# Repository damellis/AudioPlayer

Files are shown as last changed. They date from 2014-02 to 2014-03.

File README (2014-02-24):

Simple, Arduino-compatible audio player, designed to be produced using
Seeedstudio's PCBA service (http://www.seeedstudio.com/service/index.php).
Only uses parts from the Seeedstudio open parts library (OPL), including
an ATmega328, micro-SD card slot, lipo connector and charging circuit,
headphone jack, etc. The full list of parts in the OPL can be found here:
http://www.seeedstudio.com/wiki/Open_parts_library

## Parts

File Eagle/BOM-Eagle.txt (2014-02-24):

"Part";"Value";"Device";"Package";"Description";"";
"C1";"100nF";"C-0603";"C0603";"";"";
"C2";"100nF";"C-0603";"C0603";"";"";
"C3";"22pF";"C-0603";"C0603";"";"";
"C4";"22pF";"C-0603";"C0603";"";"";
"C5";"22uF";"C-POLAR-B";"AVX-B";"";"";
"C6";"10uF";"C-POLAR-A";"AVX-A";"";"";
"C7";"10uF";"C-POLAR-A";"AVX-A";"";"";
"C8";"1uF";"C-0805";"C0805";"";"";
"C9";"1uF";"C-0805";"C0805";"";"";
"C10";"100nF";"C-0603";"C0603";"";"";
"J1";"MICRO-SDCARD-CONNECTOR-3300060P1";"MICRO-SDCARD-CONNECTOR-3300060P1";"9P-SMD-W-RING";"Micro SD Card";"";
"J2";"JST-2P-SMD-PW-3410050P1";"JST-2P-SMD-PW-3410050P1";"2P-SMD-2.0-90D";"";"";
"J3";"MICRO-USB-5P-340015001";"MICRO-USB-5P-340015001";"B-SMD-5P";"ST-USB-001E：MICRO USB B SMD R/A";"";
"J4";"CONNECTOR-HEADER-2X3P-3460180P1";"CONNECTOR-HEADER-2X3P-3460180P1";"2X3P-2.54-2.54-11.6-3.0-BLACK-MALE";"";"";
"J5";"AUDIO-CONNECTOR-6P-SMD-3440030P1";"AUDIO-CONNECTOR-6P-SMD-3440030P1";"6P-SMD-3.5";"";"";
"J6";"SCREW-TERMINAL-2P-3470070P1";"SCREW-TERMINAL-2P-3470070P1";"2P-3.5";"";"";
"J7";"CONNECTOR-HEADER-6P-3460650P1";"CONNECTOR-HEADER-6P-3460650P1";"1X6P-2.54-2.54-11.6-3.0-BLACK-MALE";"";"";
"J8";"CONNECTOR-HEADER-6P-3460270P1";"CONNECTOR-HEADER-6P-3460270P1";"1X6P-2.54-8.5-BLACK-FEMALE";"";"";
"J9";"CONNECTOR-HEADER-10P-3460170P1";"CONNECTOR-HEADER-10P-3460170P1";"1X10P-2.54-8.5-YELLOW-FEMALE";"";"";
"J10";"CONNECTOR-HEADER-8P-3460290P1";"CONNECTOR-HEADER-8P-3460290P1";"1X8P-2.54-8.5-BLACK-FEMALE";"";"";
"J11";"CONNECTOR-HEADER-8P-3460290P1";"CONNECTOR-HEADER-8P-3460290P1";"1X8P-2.54-8.5-BLACK-FEMALE";"";"";
"K1";"BUTTON-4P-3100010P1";"BUTTON-4P-3100010P1";"4P-SMD-6.0X6.0X5.0H";"";"";
"R1";"4.7K";"R-0603";"R0603";"";"";
"R2";"10K";"R-0603";"R0603";"";"";
"U1";"ATMEGA328P-AU-1030060P1";"ATMEGA328P-AU-1030060P1";"TQFP32";"8-bit AVR";"";
"U2";"CN3065-1320040P1";"CN3065-1320040P1";"DFN8";"USB-Compatible Lithiumt-Ion Battery Charger with Thermal Regulation";"";
"U3";"XC6206-3.3-1300260P1";"XC6206-3.3-1300260P1";"SOT23";"LOW ESR Cap.Compatible Positive Voltage Regulators";"";
"X1";"CRYSTAL-0500290P1";"CRYSTAL-0500290P1";"2P-SMD-5.0X3.2";"";"";

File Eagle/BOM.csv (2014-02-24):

SKU | Qty | Parts
0100020P1 | 3 | C1,C2,C10
0100620P1 | 2 | C3,C4
0130240P1 | 1 | C5
0130050P1 | 2 | C6,C7
0100440P1 | 2 | C8,C9
3300060P1 | 1 | J1
3410050P1 | 1 | J2
3400150P1 | 1 | J3
3460180P1 | 1 | J4
3440030P1 | 1 | J5
3470070P1 | 1 | J6
3460650P1 | 1 | J7
3460270P1 | 1 | J8
3460170P1 | 1 | J9
3460290P1 | 2 | J10,J11
3100010P1 | 1 | K1
0010030P1 | 1 | R1
0010170P1 | 1 | R2
1030060P1 | 1 | U1
1320040P1 | 1 | U2
1300260P1 | 1 | U3
0500290P1 | 1 | X1

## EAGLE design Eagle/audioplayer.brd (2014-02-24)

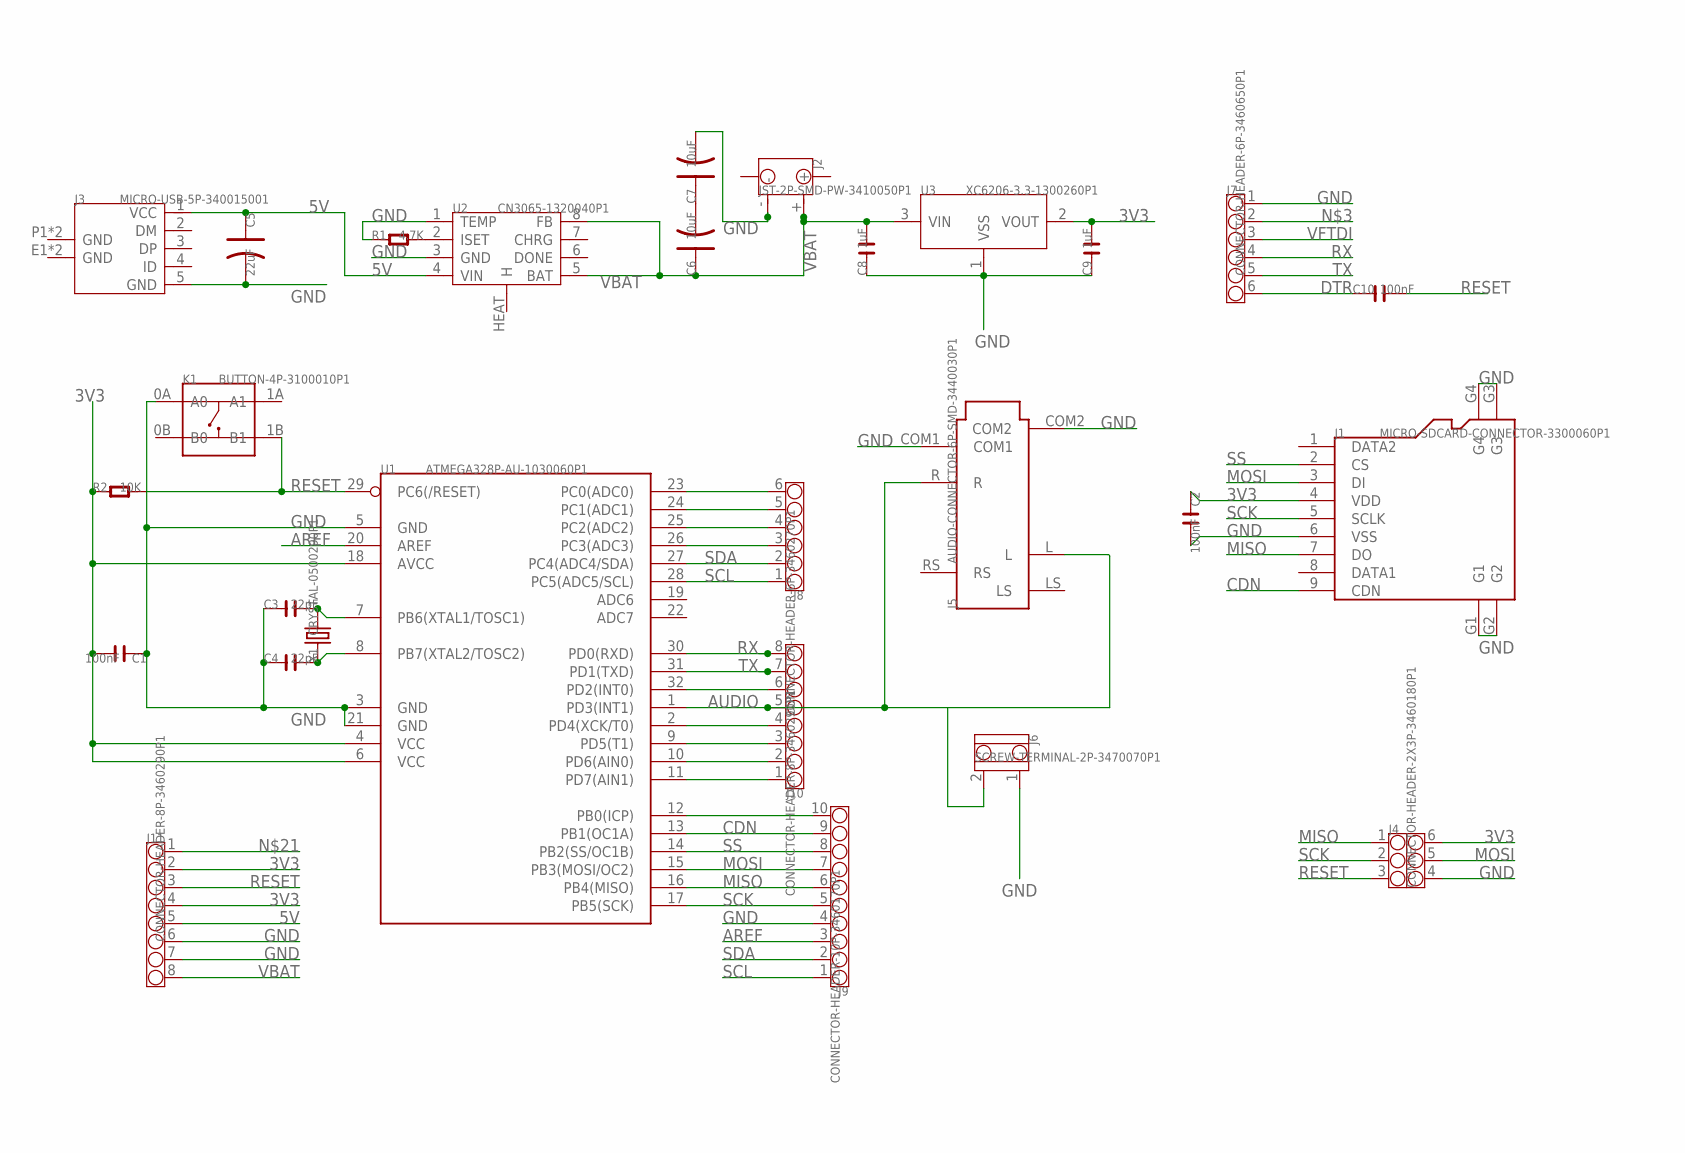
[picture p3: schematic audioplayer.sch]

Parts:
C1, C2, C10: 100nF; C0603
C3, C4: 22pF; C0603
C5: 22uF; AVX-B
C6, C7: 10uF; AVX-A
C8, C9: 1uF; C0805
J1: MICRO-SDCARD-CONNECTOR-3300060P1; 9P-SMD-W-RING
J2: JST-2P-SMD-PW-3410050P1; 2P-SMD-2.0-90D
J3: MICRO-USB-5P-340015001; B-SMD-5P
J4: CONNECTOR-HEADER-2X3P-3460180P1; 2X3P-2.54-2.54-11.6-3.0-BLACK-MALE
J5: AUDIO-CONNECTOR-6P-SMD-3440030P1; 6P-SMD-3.5
J6: SCREW-TERMINAL-2P-3470070P1; 2P-3.5
J7: CONNECTOR-HEADER-6P-3460650P1; 1X6P-2.54-2.54-11.6-3.0-BLACK-MALE
J8: CONNECTOR-HEADER-6P-3460270P1; 1X6P-2.54-8.5-BLACK-FEMALE
J9: CONNECTOR-HEADER-10P-3460170P1; 1X10P-2.54-8.5-YELLOW-FEMALE
J10, J11: CONNECTOR-HEADER-8P-3460290P1; 1X8P-2.54-8.5-BLACK-FEMALE
K1: BUTTON-4P-3100010P1; 4P-SMD-6.0X6.0X5.0H
R1: 4.7K; R0603
R2: 10K; R0603
U1: ATMEGA328P-AU-1030060P1; TQFP32
U2: CN3065-1320040P1; DFN8
U3: XC6206-3.3-1300260P1; SOT23
X1: CRYSTAL-0500290P1; 2P-SMD-5.0X3.2

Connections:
3V3: C1.2, C2.1, C9.2, J1.4 (VDD), J4.6, J11.2, J11.4, R2.1, U1.4 (VCC), U1.6 (VCC), U1.18 (AVCC), U3.2 (VOUT)
5V: C5.+ (1), J3.1 (VCC), J11.5, U2.4 (VIN)
AREF: J9.3, U1.20 (AREF)
AUDIO: J5.L, J5.R, J6.2, J10.5, U1.1 (PD3(INT1))
CDN: J1.9 (CDN), J9.9, U1.13 (PB1(OC1A))
DTR: C10.1, J7.6
GND: C1.1, C2.2, C3.1, C4.1, C5.- (2), C7.- (2), C8.1, C9.1, J1.6 (VSS), J1.G1, J1.G2, J1.G3, J1.G4, J2.-, J3.5 (GND), J4.4, J5.COM1, J5.COM2, J6.1, J7.1, J9.4, J11.6, J11.7, K1.0A (A0), R1.1, U1.3 (GND), U1.5 (GND), U1.21 (GND), U2.1 (TEMP), U2.3 (GND), U3.1 (VSS)
MISO: J1.7 (DO), J4.1, J9.6, U1.16 (PB4(MISO))
MOSI: J1.3 (DI), J4.5, J9.7, U1.15 (PB3(MOSI/OC2))
unnamed: C6.- (2), C7.+ (1)
unnamed: R1.2, U2.2 (ISET)
unnamed: J8.3, U1.26 (PC3(ADC3))
unnamed: J8.4, U1.25 (PC2(ADC2))
unnamed: J8.5, U1.24 (PC1(ADC1))
unnamed: J8.6, U1.23 (PC0(ADC0))
unnamed: J9.10, U1.12 (PB0(ICP))
unnamed: J10.1, U1.11 (PD7(AIN1))
unnamed: J10.2, U1.10 (PD6(AIN0))
unnamed: J10.3, U1.9 (PD5(T1))
unnamed: J10.4, U1.2 (PD4(XCK/T0))
unnamed: J10.6, U1.32 (PD2(INT0))
unnamed: C3.2, U1.7 (PB6(XTAL1/TOSC1)), X1.2
unnamed: C4.2, U1.8 (PB7(XTAL2/TOSC2)), X1.1
RESET: C10.2, J4.3, J11.3, K1.1B (B1), R2.2, U1.29 (PC6(/RESET))
RX: J7.4, J10.8, U1.30 (PD0(RXD))
SCK: J1.5 (SCLK), J4.2, J9.5, U1.17 (PB5(SCK))
SCL: J8.1, J9.1, U1.28 (PC5(ADC5/SCL))
SDA: J8.2, J9.2, U1.27 (PC4(ADC4/SDA))
SS: J1.2 (CS), J9.8, U1.14 (PB2(SS/OC1B))
TX: J7.5, J10.7, U1.31 (PD1(TXD))
VBAT: C6.+ (1), C8.2, J2.+, J11.8, U2.5 (BAT), U2.8 (FB), U3.3 (VIN)
VFTDI: J7.3

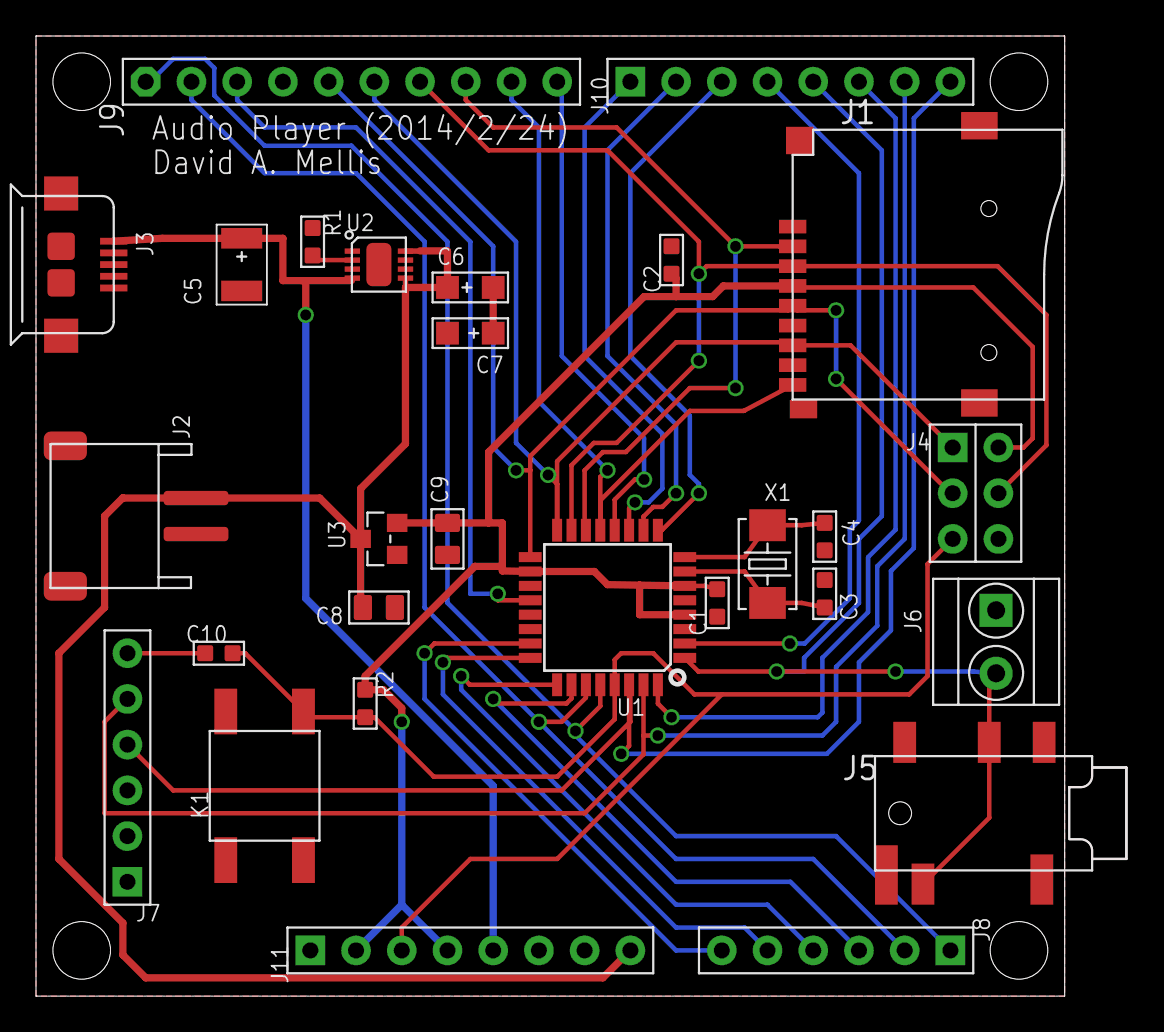
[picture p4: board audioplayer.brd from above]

Board: 4 copper layers, 60.6 x 53.3 mm, 28 parts (0 on the bottom side), 31 nets.

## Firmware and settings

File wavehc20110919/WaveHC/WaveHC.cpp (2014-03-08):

/*
 William Greiman's modified version of Ladyada's wave shield library
 I have made many changes that may have introduced bugs.  Major changes are:
 optimized DAC macros to allow 44.1 k 16-bit files
 use of FatReader to read FAT32 and FAT16 files
 modified readwavhack to be readWaveData
 use standard SD and SDHC flash cards.
 skip non-data chunks after fmt chunk
 allow 18 byte format chunk if no compression
 play stereo as mono by interleaving channels
 change method of reading fmt chunk - use union of structs
*/
#include <string.h>
#include <avr/interrupt.h>
#include <mcpDac.h>
#include <WaveHC.h>
#include <WaveUtil.h>

// verify program assumptions
#if PLAYBUFFLEN != 256 && PLAYBUFFLEN != 512
#error PLAYBUFFLEN must be 256 or 512
#endif // PLAYBUFFLEN

WaveHC *playing = 0;

uint8_t buffer1[PLAYBUFFLEN];
uint8_t buffer2[PLAYBUFFLEN];
uint8_t *playend;      // end position for current buffer
uint8_t *playpos;      // position of next sample
uint8_t *sdbuff;       // SD fill buffer
uint8_t *sdend;        // end of data in sd buffer

// status of sd
#define SD_READY 1     // buffer is ready to be played
#define SD_FILLING 2   // buffer is being filled from DS
#define SD_END_FILE 3  // reached end of file
uint8_t sdstatus = 0;

//------------------------------------------------------------------------------
// timer interrupt for DAC
ISR(TIMER1_COMPA_vect) {
  if (!playing) return;

  if (playpos >= playend) {
    if (sdstatus == SD_READY) {
    
      // swap double buffers
      playpos = sdbuff;
      playend = sdend;
      sdbuff = sdbuff != buffer1 ? buffer1 : buffer2;
      
      sdstatus = SD_FILLING;
      // interrupt to call SD reader
	    TIMSK1 |= _BV(OCIE1B);
    }
    else if (sdstatus == SD_END_FILE) {
      playing->stop();
      return;
    }
    else {
      // count overrun error if not at end of file
      if (playing->remainingBytesInChunk) {
        playing->errors++;
      }
      return;
    }
  }

  uint8_t dh, dl;
  if (playing->BitsPerSample == 16) {
  
    // 16-bit is signed
    dh = 0X80 ^ playpos[1];
    dl = playpos[0];
    playpos += 2;
  }
  else {
  
    // 8-bit is unsigned
    dh = playpos[0];
    dl = 0;
    playpos++;
  }
  
#if DVOLUME
  uint16_t tmp = (dh << 8) | dl;
  tmp >>= playing->volume;
  dh = tmp >> 8;
  dl = tmp;
#endif //DVOLUME
  
  OCR2B = dh;

//  // dac chip select low
//  mcpDacCsLow();
//  
//  // send DAC config bits
//  mcpDacSdiLow();
//  mcpDacSckPulse();  // DAC A
//  mcpDacSckPulse();  // unbuffered
//  mcpDacSdiHigh();
//  mcpDacSckPulse();  // 1X gain
//  mcpDacSckPulse();  // no SHDN
//  
//  // send high 8 bits
//  mcpDacSendBit(dh,  7);
//  mcpDacSendBit(dh,  6);
//  mcpDacSendBit(dh,  5);
//  mcpDacSendBit(dh,  4);
//  mcpDacSendBit(dh,  3);
//  mcpDacSendBit(dh,  2);
//  mcpDacSendBit(dh,  1);
//  mcpDacSendBit(dh,  0);
//  
//  // send low 4 bits
//  mcpDacSendBit(dl,  7);
//  mcpDacSendBit(dl,  6);
//  mcpDacSendBit(dl,  5);
//  mcpDacSendBit(dl,  4);
//  
//  // chip select high - done
//  mcpDacCsHigh();

}
//------------------------------------------------------------------------------
// this is the interrupt that fills the playbuffer

ISR(TIMER1_COMPB_vect) {

  // turn off calling interrupt
  TIMSK1 &= ~_BV(OCIE1B);
  
  if (sdstatus != SD_FILLING) return;

  // enable interrupts while reading the SD
  sei();
  
  int16_t read = playing->readWaveData(sdbuff, PLAYBUFFLEN);
  
  cli();
  if (read > 0) {
    sdend = sdbuff + read;
    sdstatus = SD_READY;
  }
  else {
    sdend = sdbuff;
    sdstatus = SD_END_FILE;
  }
}
//------------------------------------------------------------------------------
/** create an instance of WaveHC. */
WaveHC::WaveHC(void) {
  fd = 0;
}
//------------------------------------------------------------------------------
/**
 * Read a wave file's metadata and initialize member variables.
 *
 * \param[in] f A open FatReader instance for the wave file.
 *
 * \return The value one, true, is returned for success and
 * the value zero, false, is returned for failure.  Reasons
 * for failure include I/O error, an invalid wave file or a wave
 *  file with features that WaveHC does not support.
 */
uint8_t WaveHC::create(FatReader &f) {
  // 18 byte buffer
  // can use this since Arduino and RIFF are Little Endian
  union {
    struct {
      char     id[4];
      uint32_t size;
      char     data[4];
    } riff;  // riff chunk
    struct {
      uint16_t compress;
      uint16_t channels;
      uint32_t sampleRate;
      uint32_t bytesPerSecond;
      uint16_t blockAlign;
      uint16_t bitsPerSample;
      uint16_t extraBytes;
    } fmt; // fmt data
  } buf;
  
#if OPTIMIZE_CONTIGUOUS
  // set optimized read for contiguous files
  f.optimizeContiguous();
#endif // OPTIMIZE_CONTIGUOUS

  // must start with WAVE header
  if (f.read(&buf, 12) != 12
      || strncmp(buf.riff.id, "RIFF", 4)
      || strncmp(buf.riff.data, "WAVE", 4)) {
        return false;
  }

  // next chunk must be fmt
  if (f.read(&buf, 8) != 8
      || strncmp(buf.riff.id, "fmt ", 4)) {
        return false;
  }
  
  // fmt chunk size must be 16 or 18
  uint16_t size = buf.riff.size;
  if (size == 16 || size == 18) {
    if (f.read(&buf, size) != (int16_t)size) {
      return false;
    }
  }
  else {
    // compressed data - force error
    buf.fmt.compress = 0;
  }
  
  if (buf.fmt.compress != 1 || (size == 18 && buf.fmt.extraBytes != 0)) {
    putstring_nl("Compression not supported");
    return false;
  }
  
  Channels = buf.fmt.channels;
  if (Channels > 2) {
    putstring_nl("Not mono/stereo!");
    return false;
  }
  else if (Channels > 1) {
    putstring_nl(" Warning stereo file!");
  }
  
  BitsPerSample = buf.fmt.bitsPerSample;
  if (BitsPerSample > 16) {
    putstring_nl("More than 16 bits per sample!");
    return false;
  }
  
  dwSamplesPerSec = buf.fmt.sampleRate;
  uint32_t clockRate = dwSamplesPerSec*Channels;
  uint32_t byteRate = clockRate*BitsPerSample/8;
  
#if RATE_ERROR_LEVEL > 0
  if (clockRate > MAX_CLOCK_RATE
      || byteRate > MAX_BYTE_RATE) {
    putstring_nl("Sample rate too high!");
    if (RATE_ERROR_LEVEL > 1) {
      return false;
    }
  }
  else if (byteRate > 44100 && !f.isContiguous()) {
    putstring_nl("High rate fragmented file!");
    if (RATE_ERROR_LEVEL > 1) {
      return false;
    }
  }
#endif // RATE_ERROR_LEVEL > 0

  fd = &f;

  errors = 0;
  isplaying = 0;
  remainingBytesInChunk = 0;
  
#if DVOLUME
  volume = 0;
#endif //DVOLUME
  // position to data
  return readWaveData(0, 0) < 0 ? false: true;
}
//------------------------------------------------------------------------------
/**
 * Returns true if the player is paused else false.
 */
uint8_t WaveHC::isPaused(void) {
  cli();
  uint8_t rtn = isplaying && !(TIMSK1 & _BV(OCIE1A));
  sei();
  return rtn;
}
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

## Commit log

2014-02-06 2 hr. Basic parts and some connections.
    [audioplayer.sch]
2014-02-06 1 hr: Finished basic components and schematic.
    [audioplayer.sch]
2014-02-06 0.25 hrs: initial placement of components on board.
    [audioplayer.sch]
2014-02-11 1 hr. Add Arduino-compatible headers and redo layout (and commit brd file!).
    [audioplayer.brd, audioplayer.sch]
2014-02-13 1.5 hrs: routing.
    [audioplayer.brd, audioplayer.sch]
2014-02-20 2 hrs. Routing the rest of the traces. Fix reset button.
    [audioplayer.brd, audioplayer.sch]
2014-02-21 0.5 hrs: extend outline, add drill holes, adjust traces and components.
    [audioplayer.brd]
2014-02-21 0.25 hours: silkscreen and move FTDI header.
    [audioplayer.brd]
2014-02-24 0.5 hrs: improve trace and via spacing, move ATmega capacitor, update date.
    [audioplayer.brd]
2014-02-24 1 hr. Generate gerbers and BOM. Order boards.
    [BOM.csv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]
2014-03-08 0 hrs. Move hardware files into Eagle/ directory.
    [BOM.csv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]
2014-03-08 1.75 hrs. Test board and get audio playback working.
    Modifying the wavehc library to use PWM output on pin 3 (OCR2B) instead of via a DAC.
